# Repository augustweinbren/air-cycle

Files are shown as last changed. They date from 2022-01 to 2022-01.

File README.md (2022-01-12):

**Table of Contents**
- [Description ](#description-)
- [Items Needed ](#items-needed-)
- [Installations and Software Setups ](#installations-and-software-setups-)
- [Recommended order of Arduino deployments ](#recommended-order-of-arduino-deployments-)
- [Enclosure ](#enclosure-)
## Description 
This directory contains everything needed to develop a BLE-enabled particulate matter monitor and 3D print a case and mount for a bicycle. 

## Items Needed 

*Electronic parts*
- [Arduino WiFi Rev2](http://store.arduino.cc/products/arduino-uno-wifi-rev2) (Optional)
- [ESP32](https://www.amazon.co.uk/gp/product/B071JR9WS9/ref=ppx_yo_dt_b_search_asin_title?ie=UTF8&psc=1)
- [NeoPixel Stick](https://www.adafruit.com/product/1426)
- [Plantower PMS5003](https://shop.pimoroni.com/products/pms5003-particulate-matter-sensor-with-cable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)
- [Particulate Matter Sensor Breakout (for PMS5003)](https://shop.pimoroni.com/products/particulate-matter-sensor-breakout)
- Female-female jumper cables
- Header pins
- [Stripboard 64 x 95mm, 24 Tracks, 37 Holes](https://www.betterequipped.co.uk/stripboard-64-x-95mm-24-tracks-37-holes-4224)
- Power bank
- At least two breadboards (two are needed due to ESP32's width)

*Hand Tools*
- [Stripboard Track Cutter](https://thepihut.com/products/stripboard-track-cutter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)
- Soldering iron

*Enclosure*
- 3D Printer + PLA Filament
- 3 cable ties
- Rubber bands for additional support

## Installations and Software Setups 
1.	Download and install [Arduino IDE](https://www.arduino.cc/en/software)
2.	[Set up a GitHub repo](https://docs.github.com/en/get-started/quickstart/create-a-repo) for the project
3. [Install the ESP32 module for Arduino IDE](https://randomnerdtutorials.com/installing-the-esp32-board-in-arduino-ide-windows-instructions/)
4. Install the following Arduino libraries:
   * [Arduino BLE](https://www.arduino.cc/en/Reference/ArduinoBLE)
   * [Software Serial](https://www.arduino.cc/en/Reference/SoftwareSerial)
   * [PM 2.5 AQI](https://github.com/adafruit/Adafruit_PM25AQI)
   * [Adafruit NeoPixel](https://learn.adafruit.com/adafruit-neopixel-uberguide/arduino-library-installation)
   * [EEPROM](https://www.arduino.cc/en/Reference/EEPROM)
5. Set up your 3D modelling and printing software--this will depend on the particular modelling and printing software you are using
6. [Download LightBlue](https://punchthrough.com/lightblue/)
7. [Set up Adafruit IO](https://learn.adafruit.com/welcome-to-adafruit-io/getting-started-with-adafruit-io)

## Recommended order of Arduino deployments 
The following order of software uploads via the Arduino IDE is recommended:
1. `pm25Bluetooth`
2. `Blink_ESP32`
3. `pm25_neopixel_esp32`
4. `pm25_neopixel_esp32_eeprom`
5. `pm25_neopixel_esp32_bt_eeprom`

## Enclosure 
Note: it is not suggested to create an enclosure until a stripboard prototype is tried and tested. A step-by-step guide can be found in the [pm25_neopixel_esp32 directory](https://github.com/augustweinbren/air-cycle/tree/master/pm25_neopixel_esp32).

1. Plug the prototype into the power bank using a USB cable, and confirm that the NeoPixel LEDs are at least partially lit up.
2. Position the power bank atop the PMS5003.
3. Measure the width, height, and depth of the prototype + power bank, ideally with a digital caliper for added precision.
4. Add 3 mm to each dimension to ensure adequate space is available and note these dimensions for the inside of a 3d-printed box. Add another 2 mm for the dimensions of the outside of the box.
5. [Design a box in Fusion 360](https://www.youtube.com/watch?v=HDJ2g19SlCI)
6. [Make one side meshed to allow air to flow into the Plantower](https://www.youtube.com/watch?v=Kj6h6ARtITE&t=176s). This side will be faced towards the cyclist to reduce distortion induced by the PMS5003's fan.
7. 3D Print this box, and ensure that your powered device fits inside of it with the power bank closest to the opening.
8. If the device fits in the box, take measurements for your mount. The mount I printed in this project has three points of support: one at the middle of the stem, and two on the handlebar. A gap needs to be left for the stem's handlebar mount. Take the following measurements:
   * Length and width of the stem's handlebar mount
   * Height difference between the top of the handlebar mount and the tops of both stem and the handlebar at its lowest point (if your handlebar has curvature). Note down whichever height difference is greater.
   * Width of the stem at the approximate point of support
   * Width of the handlebar at the approximate points of support
9.  Return to your 3D Modelling software and produce the base with the following considerations:
    * To fit the boxed device securely, the base will need a .3 mm larger width and length than that of the outer dimensions of the box
    * Vault the edges of the supports slightly for added stability
    * Create a hole within each of the three supports to fit cable ties to create three supports in two axes of rotation
10. Once the base is fully printed, it can be mounted on the bicycle with the cable ties.
11. Carefully place the box upside-down on the mount, preventing the contents from falling out
12. Rubber bands were additionally used during test rides to secure the mount to the base.

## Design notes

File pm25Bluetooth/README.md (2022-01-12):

Note: this prototype is an optional first step prior to redevelopment using an ESP32.

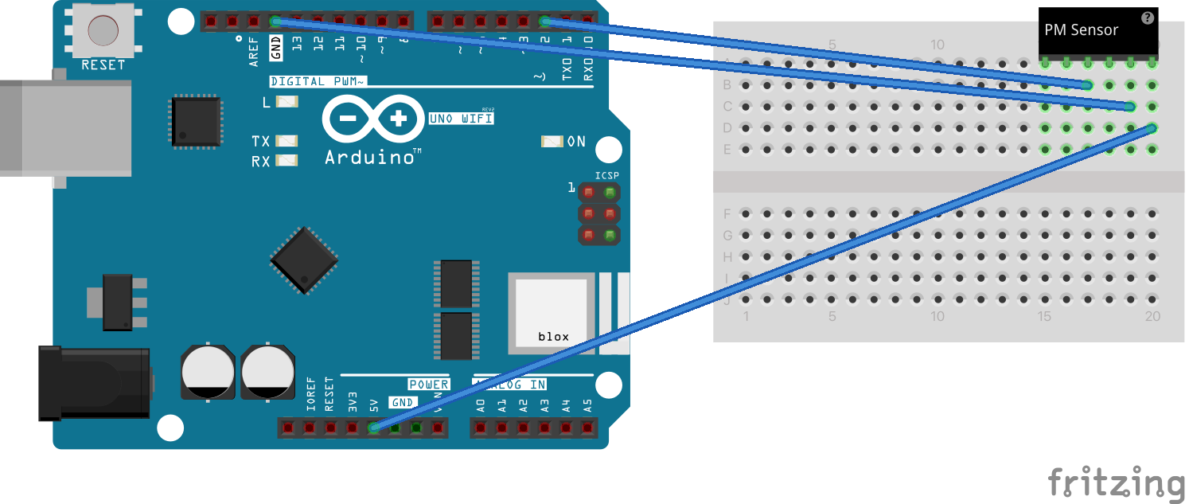
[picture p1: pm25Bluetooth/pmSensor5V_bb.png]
Arduino Uno PM Sensor
Start by emplacing the components on a breadboard: 

Prior to uploading the Arduino code, it is recommended that you randomise the Bluetooth Service and Characteristic keys, as these should be unique identifiers.

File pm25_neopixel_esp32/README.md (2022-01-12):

Follow the following steps:

1. As a NeoPixel is in use in this example, you will need to solder a set of four jumper pins onto its input end.
2. After the NeoPixel has been prepared, you can prototype this version on a breadboard:
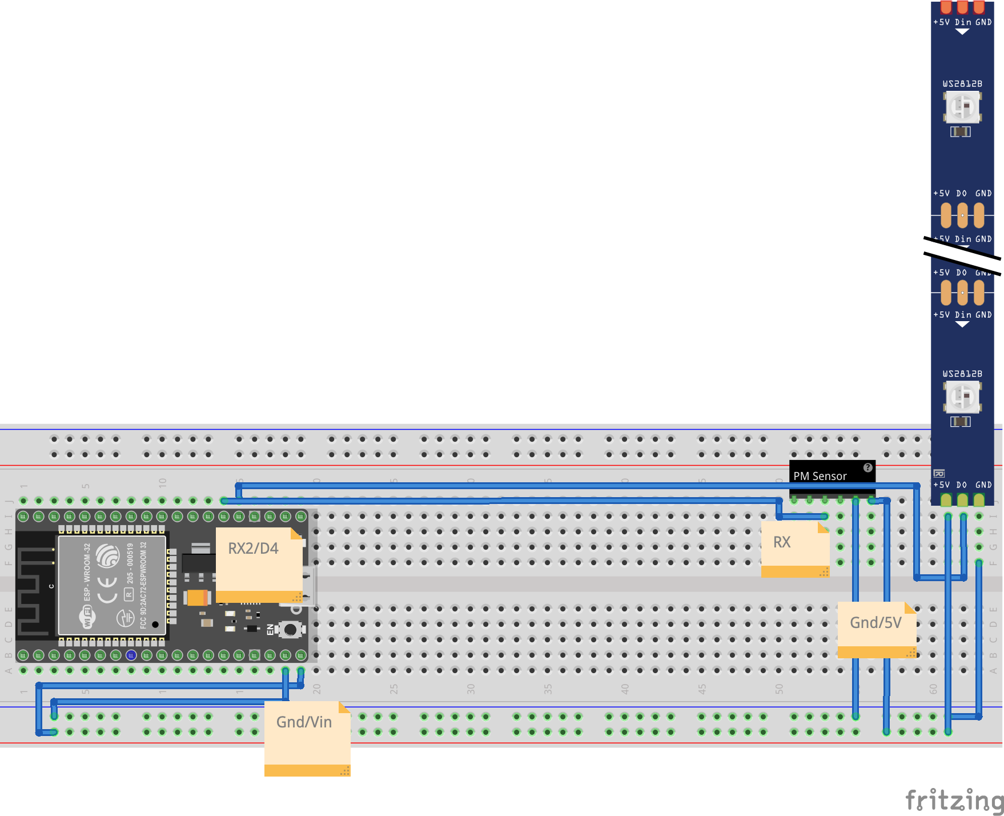
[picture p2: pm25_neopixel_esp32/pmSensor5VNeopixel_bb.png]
breadboard-based prototype
   
3. Upload `pm25_neopixel_esp32.ino` to your ESP32 microcontroller.
4. Build the stripboard-based prototype:
   *  Solder 14 jumper pins onto the stripboard
   *  Solder the ESP32 onto the stripboard
   *  Solder the PM Breakout to the stripboard

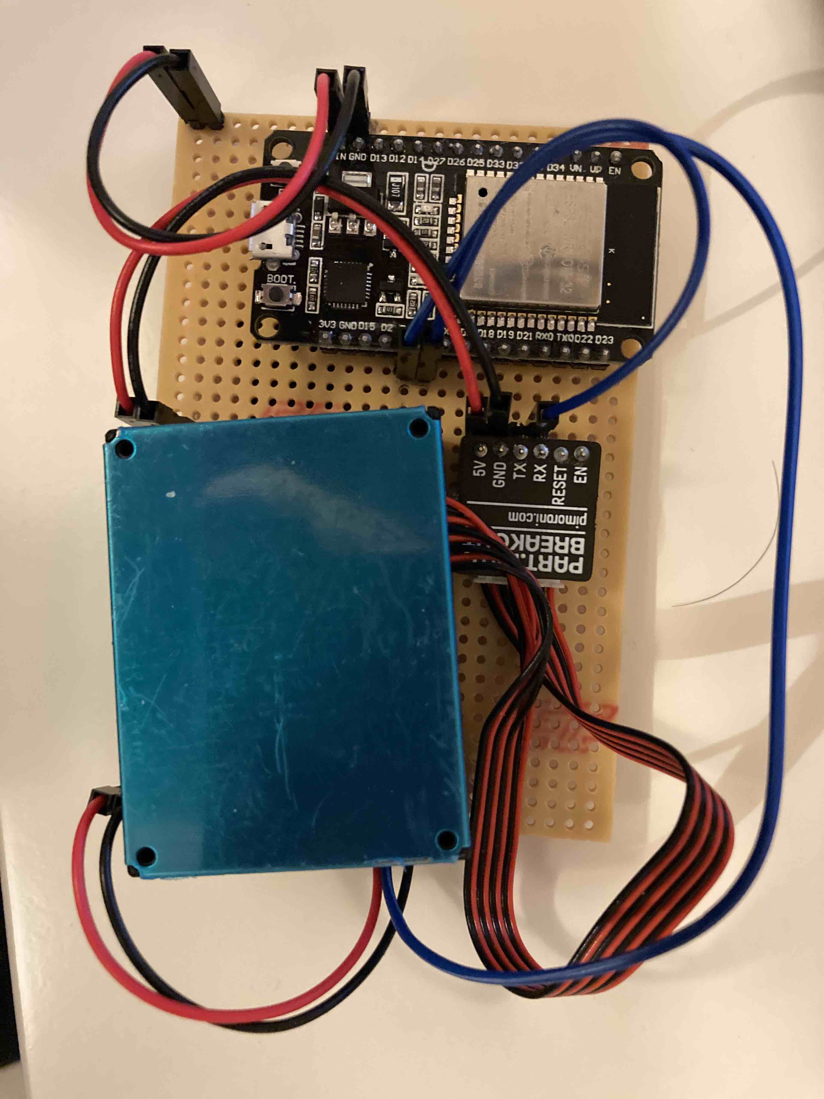
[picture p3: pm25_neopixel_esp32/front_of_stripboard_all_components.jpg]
stripboard-front-soldered-components

   *  Create gaps in the board using a hand drill to prevent short circuiting
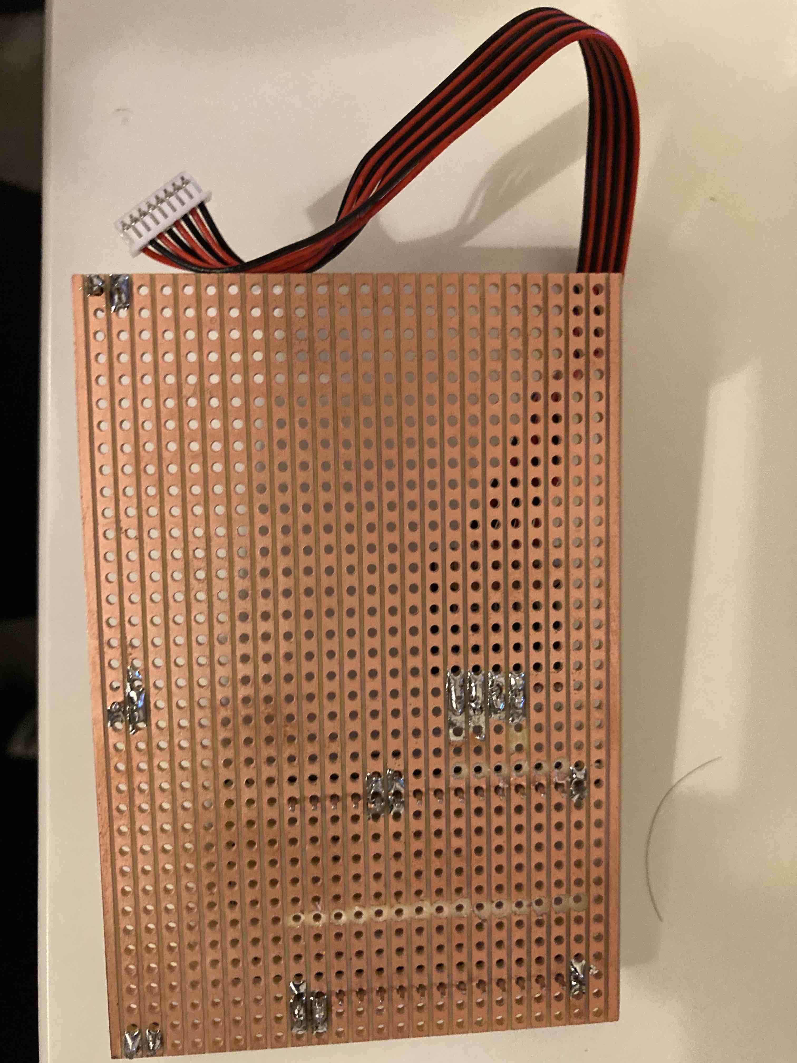
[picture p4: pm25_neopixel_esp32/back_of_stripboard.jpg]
stripboard-back-soldered-components

   *  Add all of the non-soldered components: connect the particulate matter breakout board to the PMS5003 sensor and wire both the header pins and the neopixel using female-female cables
   * Test again that the device works as it did on the breadboard. Plug in the ESP32 to a 5V power source (such as a computer's USB port) to test that the Neopixel is still lighting up similarly to how it did in the breadboard prototype.
   * Secure the PMS5003 by placing a roll of transparent tape underneath it and wedging it between different header pins.
stripboard-front-all-components
   * Insulate the non-illuminating side of the neopixel using electrical tape.
   * Secure the NeoPixel (LEDs faced away) to the copper side of the stripboard using transparent tape
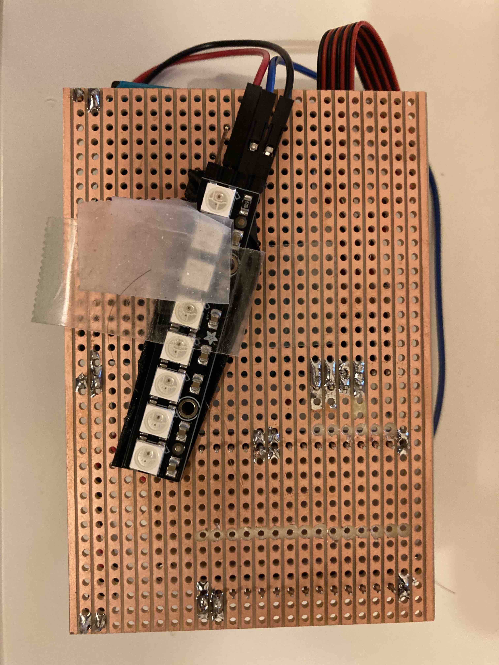
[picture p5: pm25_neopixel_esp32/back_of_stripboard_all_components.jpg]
back-of-stripboard-all-components


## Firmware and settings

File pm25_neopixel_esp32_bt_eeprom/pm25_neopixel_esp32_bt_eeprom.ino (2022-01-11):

/* Test sketch for Adafruit PM2.5 sensor with  
  BLE code adapted from BLE_server example
  (https://randomnerdtutorials.com/esp32-bluetooth-low-energy-ble-arduino-ide/)
*/
#include "Adafruit_PM25AQI.h"
#include <Adafruit_NeoPixel.h>
#include <BLEDevice.h>
#include <BLEServer.h>
#include <BLEUtils.h>
#include <BLE2902.h>
#include <EEPROM.h>

#define PIXELPIN 4
#define NUMPIXELS 8
#define SERVICE_UUID "c867682e-d8aa-4bf3-ba43-aa2ed0a24abf"
#define PM10_UUID "d5212717-dd8e-4710-a332-ab35a282ba7c"
#define PM25_UUID "486c7b93-7fd5-43cc-8a17-b32a6cf4d8ab"
#define PM100_UUID "6f440878-5a1a-4a76-819a-3e64f73098dd"

BLEServer* pServer = NULL;
BLECharacteristic* pm10Characteristic = NULL;
BLECharacteristic* pm25Characteristic = NULL;
BLECharacteristic* pm100Characteristic = NULL;
bool deviceConnected = false;
bool oldDeviceConnected = false;
uint16_t pm10Value = 0;
uint16_t pm25Value = 0;
uint16_t pm100Value = 0;

Adafruit_PM25AQI aqi = Adafruit_PM25AQI();
Adafruit_NeoPixel pixels(NUMPIXELS, PIXELPIN);
float elapsedSecondsSinceLastWrite = 0;
int days = 0;
int hours = 0;
int tenMinuteInts = 0;
int minutes;


class MyServerCallbacks: public BLEServerCallbacks {
    void onConnect(BLEServer* pServer) {
      deviceConnected = true;
    };

    void onDisconnect(BLEServer* pServer) {
      deviceConnected = false;
    }
};

void setup() {
  long startOfSetup = millis();

  pixels.begin();
  days = EEPROM.read(0);
  hours = EEPROM.read(1);
  tenMinuteInts = EEPROM.read(2);
  minutes = tenMinuteInts * 10;
  EEPROM.write(0, 0);
  EEPROM.write(1, 0);
  EEPROM.write(2, 0);
  // Wait for serial monitor to open
  Serial.begin(115200);
 
  
  Serial2.begin(9600);
  while (!Serial) { delay(10); }
  while (!Serial2) { delay(10); }

  if (days != 255) { // 255 means the eeprom memory is empty
    Serial.println("Total previous uptime [Days/Hours/Minutes]: ");
    Serial.println(days);
    Serial.println(hours);
    Serial.println(minutes);
  }
  days = 0;
  hours = 0;
  tenMinuteInts = 0;
  Serial.println("Adafruit PMSA003I Air Quality Sensor");

  // Wait one second for sensor to boot up!
  delay(1000);

  if (! aqi.begin_UART(&Serial2)) { // connect to the sensor over hardware serial
    Serial.println("Could not find PM 2.5 sensor!");
    while (1) { delay(10); }
  }

  Serial.println("PM25 found!");
  Serial.println("Setting up BLE...");
  BLEDevice::init("ESP32 PM Sensor");
  
  pServer = BLEDevice::createServer();
  pServer->setCallbacks(new MyServerCallbacks());
  
  BLEService *pService = pServer->createService(SERVICE_UUID);
  
  pm10Characteristic = pService->createCharacteristic(
    PM10_UUID,
    BLECharacteristic::PROPERTY_READ |
    BLECharacteristic::PROPERTY_NOTIFY);
    //notify used because speed more important than reliability (UDB vs TCP)

  pm10Characteristic -> addDescriptor(new BLE2902()); //  allow server-initiated updates (https://www.oreilly.com/library/view/getting-started-with/9781491900550/ch04.html)
  
  pm25Characteristic = pService->createCharacteristic(
    PM25_UUID,
    BLECharacteristic::PROPERTY_READ |
    BLECharacteristic::PROPERTY_NOTIFY);
  pm25Characteristic -> addDescriptor(new BLE2902()); //allow server-initiated updates (https://www.oreilly.com/library/view/getting-started-with/9781491900550/ch04.html)
  
  pm100Characteristic = pService->createCharacteristic(
    PM100_UUID,
    BLECharacteristic::PROPERTY_READ |
    BLECharacteristic::PROPERTY_NOTIFY);
  pm100Characteristic -> addDescriptor(new BLE2902()); //allow server-initiated updates (https://www.oreilly.com/library/view/getting-started-with/9781491900550/ch04.html)
  
  pService->start();
  BLEAdvertising *pAdvertising = BLEDevice::getAdvertising();
  pAdvertising->addServiceUUID(SERVICE_UUID);
  pAdvertising->setScanResponse(true);
  pAdvertising->setMinPreferred(0x06); // functions that help with iPhone connections issue
  pAdvertising->setMaxPreferred(0x12); // See "advertising interval" for BLE
  BLEDevice::startAdvertising();
  Serial.println("Waiting for a client connection to notify...");
  
  long endOfSetup = millis();
  int setupMillis = endOfSetup - startOfSetup;
  elapsedSecondsSinceLastWrite = setupMillis / 1000.0;
}

void loop() {
  long startOfLoop = millis();

  if (elapsedSecondsSinceLastWrite >= 600.0) {
    tenMinuteInts++;
    elapsedSecondsSinceLastWrite -= 600.0;
    if (tenMinuteInts == 6) {
      hours++;
      tenMinuteInts = 0;
      if (hours == 24) {
        days++;
        hours = 0;
        EEPROM.write(0, days);
      }
      EEPROM.write(1, hours);
    }
    EEPROM.write(2, tenMinuteInts);
  }
  
  pixels.clear();

  PM25_AQI_Data data;
  
  if (! aqi.read(&data)) {
    Serial.println("Could not read from AQI");
    delay(1000);  // try again in a bit!
    long endOfLoop = millis();
    int loopMillis = endOfLoop - startOfLoop;
    elapsedSecondsSinceLastWrite += (loopMillis / 1000.0);
    return;
  }
  Serial.println("AQI reading success");
  uint32_t color;
  int bitCount;
  if (data.pm25_standard <= 50) {
    color = 0x00FF00; // green
    bitCount = map(data.pm25_standard, 0, 50, 1, NUMPIXELS + 1);
  } else if (data.pm25_standard <= 100) {
    color = 0xFFFF00; //yellow
    bitCount = map(data.pm25_standard, 51, 100, 1, NUMPIXELS + 1);
  } else if (data.pm25_standard <= 150) {
    color = 0xFF8000; // orange
    bitCount = map(data.pm25_standard, 101, 150, 1, NUMPIXELS + 1);
  } else if (data.pm25_standard <= 200) {
    color = 0xFF0000; // red
    bitCount = map(data.pm25_standard, 151, 200, 1, NUMPIXELS + 1);
  } else {
    color = 0x7F00FF; //Purple
    bitCount = map(data.pm25_standard, 201, 300, 1, NUMPIXELS + 1);
  }

  // bitCount shown has a slight possibility of being larger than the number of pixels,
  // so needs to be capped
  Serial.print("NEOPIXEL pixel count: ");
  Serial.println(bitCount);
  if (bitCount >= NUMPIXELS) {
    pixels.fill(color);
  } else {
    pixels.fill(color, 0, bitCount);
  }
  pixels.show();


  Serial.println();
  Serial.println(F("---------------------------------------"));
  Serial.println(F("Concentration Units (standard)"));
  Serial.println(F("---------------------------------------"));
  Serial.print(F("PM 1.0: ")); Serial.print(data.pm10_standard);
  Serial.print(F("\t\tPM 2.5: ")); Serial.print(data.pm25_standard);
  Serial.print(F("\t\tPM 10: ")); Serial.println(data.pm100_standard);
  Serial.println(F("Concentration Units (environmental)"));
  Serial.println(F("---------------------------------------"));
  Serial.print(F("PM 1.0: ")); Serial.print(data.pm10_env);
  Serial.print(F("\t\tPM 2.5: ")); Serial.print(data.pm25_env);
  Serial.print(F("\t\tPM 10: ")); Serial.println(data.pm100_env);
  Serial.println(F("---------------------------------------"));
  Serial.print(F("Particles > 0.3um / 0.1L air:")); Serial.println(data.particles_03um);
  Serial.print(F("Particles > 0.5um / 0.1L air:")); Serial.println(data.particles_05um);
  Serial.print(F("Particles > 1.0um / 0.1L air:")); Serial.println(data.particles_10um);
  Serial.print(F("Particles > 2.5um / 0.1L air:")); Serial.println(data.particles_25um);
  Serial.print(F("Particles > 5.0um / 0.1L air:")); Serial.println(data.particles_50um);
  Serial.print(F("Particles > 10 um / 0.1L air:")); Serial.println(data.particles_100um);
  Serial.println(F("---------------------------------------"));

  if (deviceConnected) {
    Serial.println("Client connected");
    pm10Value = data.pm10_standard;
    pm10Characteristic -> setValue((uint8_t*)&pm10Value, 2);
    pm10Characteristic -> notify();
    pm25Value = data.pm25_standard;
    pm25Characteristic -> setValue((uint8_t*)&pm25Value, 2);
    pm25Characteristic -> notify();
    pm100Value = data.pm100_standard;
    pm100Characteristic -> setValue((uint8_t*)&pm100Value, 2);
    pm100Characteristic -> notify();
    delay(10000);
  }

  if (!deviceConnected && oldDeviceConnected) {
    Serial.println("Client disconnected");
    delay(500);
    pServer->startAdvertising();
    Serial.println("Advertising again");
    oldDeviceConnected = false;
  }

  if (deviceConnected && !oldDeviceConnected) {
    Serial.println("Client connected");
    oldDeviceConnected = true;
  }


  long endOfLoop = millis();
  int loopMillis = endOfLoop - startOfLoop;
  elapsedSecondsSinceLastWrite += (loopMillis / 1000.0);
}

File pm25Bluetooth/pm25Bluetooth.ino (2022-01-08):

/* 
 * This sketch collects PM measurements and sends them via the Arduino WiFi Rev2
 * using Bluetooth Low Energy. BLE Code is adapted from ButtonLED example.
 * 
 * \note Please generate randomised values for the service and characteristic keys */
#include "Adafruit_PM25AQI.h"
#include <ArduinoBLE.h>

// If your PM2.5 is UART only, for UNO and others (without hardware serial) 
// we must use software serial...
// pin #2 is IN from sensor ("RX" on breakout), leave pin #3 disconnected

// Using software serial to transmit PM measurements for convenience
#include <SoftwareSerial.h>
SoftwareSerial pmSerial(2, 3); //(resp.) RX, TX

// Initialising service and characteristics. As mentioned above, please randomise the keys
BLEService pmService("c867682e-d8aa-4bf3-ba43-aa2ed0a24abf");
BLEByteCharacteristic pm10Characteristic(
  "d5212717-dd8e-4710-a332-ab35a282ba7c", BLERead | BLENotify);
BLEByteCharacteristic pm25Characteristic(
  "486c7b93-7fd5-43cc-8a17-b32a6cf4d8ab", BLERead | BLENotify);
BLEByteCharacteristic pm100Characteristic(
  "6f440878-5a1a-4a76-819a-3e64f73098dd", BLERead | BLENotify);

Adafruit_PM25AQI aqi = Adafruit_PM25AQI();

// Used to time the delay between measurements
long prevMillis = 0;

void setup() {
  // Wait for serial monitor to open
  Serial.begin(115200);
  while (!Serial) delay(10);

  if (!BLE.begin()) {
    Serial.println("Starting BLE failed!");
    while(1);
  }
  Serial.println("Starting BLE Succeeded");

  BLE.setLocalName("PMSensor");
  BLE.setAdvertisedService(pmService);

  pmService.addCharacteristic(pm10Characteristic);
  pmService.addCharacteristic(pm25Characteristic);
  pmService.addCharacteristic(pm100Characteristic);

  
  BLE.addService(pmService);

  pm10Characteristic.writeValue(0);
  pm25Characteristic.writeValue(0);
  pm100Characteristic.writeValue(0);
  BLE.advertise();
  Serial.println("Bluetooth active and waiting for connection");

  Serial.println("Adafruit PMSA003I Air Quality Sensor");

  // Wait one second for sensor to boot up!
  delay(1000);

  pmSerial.begin(9600);

  if (! aqi.begin_UART(&pmSerial)) { // connect to the sensor over software serial 
    Serial.println("Could not find PM 2.5 sensor!");
    while (1) delay(10);
  }

  Serial.println("PM25 found!");
}
void loop() {
  // Check if a device has been connected
  BLE.poll();
  // Query the central device (in this case the smartphone)
  BLEDevice central = BLE.central();
  

  // If there is a central device connected
  if (central) {
    Serial.println("Central Address");
    Serial.println(central.address());
    // Query the central device again and return true if still connected
    while (central.connected()) {
      long currentMillis = millis();
      // only update data at max every 3 seconds
      if (currentMillis - prevMillis >= 3000) {
        prevMillis = currentMillis;
        updatePM();
      }
    }
  }
    Serial.print("Disconnected from central: ");
    Serial.println(central.address());

}

void updatePM() {
    PM25_AQI_Data data;
    // if unable to read data from aqi
    if (! aqi.read(&data)) {
      // query connection status to prevent timing out
      BLE.central().connected();
      Serial.println("Could not read from AQI");
      return; // try again next cycle!
    }
    // if the smartphone is no longer connected over ble
    if(!((BLE.central()).connected())) {
      return;
    }
    Serial.println("AQI reading success");
  
    Serial.println();
    Serial.println(F("---------------------------------------"));
    Serial.println(F("Concentration Units (standard)"));
    Serial.println(F("---------------------------------------"));
    Serial.print(F("PM 1.0: ")); Serial.print(data.pm10_standard);
    // query to avoid timing out
    BLE.central().connected();
    pm10Characteristic.writeValue(data.pm10_standard);
    Serial.print(F("\t\tPM 2.5: ")); Serial.print(data.pm25_standard);
    // query to avoid timing out
    BLE.central().connected();
    pm25Characteristic.writeValue(data.pm25_standard);
    Serial.print(F("\t\tPM 10: ")); Serial.println(data.pm100_standard);
    // query to avoid timing out
    BLE.central().connected();
    pm100Characteristic.writeValue(data.pm100_standard);
    // query to avoid timing out
    BLE.central().connected();
    Serial.println("BLUETOOTH WRITTEN");
}

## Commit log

2021-11-26 working PM concentrations. Timing out on interrogation by light blue
    [pmSensorAttachedNoWifi.fzz]
2021-12-01 more fritzing diagrams; more connected() lines
    [pmSensor3V.fzz, pmSensor5V.fzz, pmSensorAttachedNoWifi.fzz]
2021-12-07 3d printed enclosure (v1)
2021-12-07 esp32--no BT
2021-12-10 New fritzing
    [pmSesnor5VNeopixel.fzz]
2021-12-28 Final fritzing?
    [pmSesnor5VNeopixel.fzz]
2021-12-28 moved delay to only if a device was connected
2022-01-11 Arduino prototype readme
2022-01-12 READMEs + Cleanups
    [pmSensor3V.fzz, pmSensorAttachedNoWifi.fzz]
2022-01-12 Moved enclosure README into main one
